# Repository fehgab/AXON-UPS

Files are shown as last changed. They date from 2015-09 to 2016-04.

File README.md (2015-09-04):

AXON-UPS
========

## Introduction

AXON-UPS is a sigle-board-computer, which acts as a functional unit.
Its main purpose to provide intelligent UPS functionality to linux based single board computers, such as Raspberry Pi, Banana Pi, Orange Pi, Cubieboard, etc.

This device is a tiny member of the big family of intelligent UPSs that is a wide range of devices from simple desktop variants to the professional server UPSs.
It is developed as a thesis work, but the developer is willing to create a product, that is able to delivers real values to real customers. So the functionalities of the several releases of the product will be collected from potential users of it.
    
This document summerize the whole project, including the requirements specification, the development roadmap and some references to existing alternatives of the product and solutions might worth to study during the design phase.

## Roadmap

1. Definition of the thesis topic

    - Deadline: 01.09.2015

2. Phase I:

    - Scouting, reading literature, collecting ideas, existing solutions, etc.

    - Defining the features, release planning

    - Designing the device, start development:

        - schematics of the circuit
        - breadboard prototype
        - firmware/software
        - prototype testing

    - Deadline:
        dec 15

2. Phase II:
    - Finish development:

        - PCB layout

    - Manufacturing and assembling the PCBs (prototype)
    - Testing
    - Completed documentation, finished thesis work
    - Deliver the working v1.0 product
    - Deadline: június 30

## Next Actions

- Involving potential product end-users into the requirement specification
- Collecting ideas and required features

    - Collecting and studying Universal UPS features, functionalities
    - Study the unix upsd and similar tools

- Defining the scope for v1.0 product

## Requirements

### Mandatory

- AXON-UPS must provide the regulated (configurable) voltage and current to the connected devices:

    - Voltages:
        - 5 VDC
        - 3.3 VDC
    - Current: min. 3A

- Power Outage Detection and management:
    - In case of outage a controlled switch-off procedure must be executed successfully
    - In case of outage the UPS must be able to supply the host computer until that is successfully shut down.
    - Time and mode is configurable
    - Auto-shut down mode:
        - shut down immediately (timing is configurable),
        - keep-alive mode until there is enough power, then shut-down.

- Intentional switch on/off process management:

    - Execute the startup and shut-down process in case of order: switch ON/OFF (mechanical, remote command).

    - via...
        - mechanical switch,
        - remote command.

- In case the shut-down process has been started either intentionally or via power outage, the swithch on/off can be activated only after the ongoing shut-down process successfully finished.

- Display/monitor status:

    - LED,
    - software,
    - configurable.

- USB communication channel with serial protocol:

    - communicates with the host computer,
    - configurability,
    - alert/watch-dog function,
    - log transfer,
    - etc.

- Configurability via
    - firmware
    - jumpers

### Optional

- Supervise and log the outages, brown-outs, 
- Interrupt jumper/connector  to rPi GPIO, etc.
- ROS compatible
- Using solar cells 

## References

- [Raspberry Pi UPS: A Very Simple Solution](http://homediyelectronics.com/projects/raspberrypi/ups/)
- [Belkin Universal UPS protocol description](http://www.mscs.dal.ca/~selinger/ups/belkin-universal-ups.html)
- [Network UPS Tools](https://en.wikipedia.org/wiki/Network_UPS_Tools)
- [V-USB - A software-only implementation of a low-speed USB device for Atmel’s AVR®](https://www.obdev.at/products/vusb/index.html)
- [Controlled Shutdown at Power Failure](https://www.raspberrypi.org/forums/viewtopic.php?f=37&t=50470)

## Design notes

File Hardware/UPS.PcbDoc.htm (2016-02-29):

Reporting Options

# File in Previous Format

Date | : | 2016.02.29.
Time | : | 16:59:47
Filename | : | D:\Cloud\Github\AXON-UPS\Hardware\UPS.PcbDoc

Version | Warning

This file was generated by an earlier version of the software

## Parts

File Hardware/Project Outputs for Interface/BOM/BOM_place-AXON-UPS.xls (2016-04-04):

Designator | CompType | Value | Package | Note | Distributor | Order Code | Comment | Description | Lomex NR
B1 |  |  |  |  |  |  | BAT
C1 |  | 100nF |  |  |  |  | 100nF | Capacitor | 82-07-32
C2 |  | 100nF |  |  |  |  | 100nF | Capacitor | 82-07-32
C3 |  | 100nF |  |  |  |  | 100nF | Capacitor | 82-07-32
C4 |  | 100nF |  |  |  |  | 100nF | Capacitor | 82-07-32
C5 | CC0805KRX7R9BB472 | 4n7 50V X7R | 0805 |  | Lomex | 82-00-71 | 4n7 50V X7R | SMD kondenzátorok
C6 | CC0805KRX7R9BB472 | 4n7 50V X7R | 0805 |  | Lomex | 82-00-71 | 4n7 50V X7R | SMD kondenzátorok
C7 |  | 6800uF |  |  |  |  | 5600uF | Capacitor
C8 |  | 10uF |  |  |  |  | 10uF | Capacitor | 82-08-32
C9 |  | 47uF |  |  |  |  | 47uF | Capacitor | 82-08-04
C10 |  | 100nF |  |  |  |  | 100nF | Capacitor | 82-07-32
C11 |  | 100nF |  |  |  |  | 100nF | Capacitor | 82-07-32
C12 |  | 10uF |  |  |  |  | 10uF | Capacitor | 82-08-32
C13 |  | 10uF |  |  |  |  | 10uF | Capacitor | 82-08-32
C14 |  | 1u2 |  |  |  |  | 1u2 | Capacitor | 82-05-93
C15 |  | 100nF |  |  |  |  | 100nF | Capacitor | 82-07-32
C16 |  | 1u2 |  |  |  |  | 1u2 | Capacitor | 82-05-93
C17 |  | 1nF |  |  |  |  | 1nF | Capacitor | 82-00-75
C18 |  | 22pF |  |  |  |  | 22pF | Capacitor | 82-09-18
C19 |  | 22pF |  |  |  |  | 22pF | Capacitor | 82-09-18
C20 |  | 100nF |  |  |  |  | 100nF | Capacitor | 82-07-32
C21 |  | 1uF |  |  |  |  | 1uF | Capacitor | 82-05-11
C22 |  | 10uF |  |  |  |  | 10uF | Capacitor | 82-08-32
C23 |  | 10uF |  |  |  |  | 10uF | Capacitor | 82-08-32
C24 |  | 10nF |  |  |  |  | 10nF | Capacitor | 82-05-66
C25 |  | 10nF |  |  |  |  | 10nF | Capacitor | 82-05-66
C26 | CC0805KPX7R9BB104 | 100nF 50V | 0805 | 10% X7R | Lomex | 82-07-32 | 100nF 50V | SMD kondenzátorok
C27 | CL31A106KAHNNNE | 10uF 25V | 1206 | 10% X5R | Lomex | 82-07-90 | 10uF 25V | SMD kondenzátorok
C28 | CC0805KRX7R8BB103 | 10nF 10% 25V X7R | 0805 |  | Lomex | 82-05-66 | 10nF 10% 25V X7R | SMD kondenzátorok
C29 | CC0805KPX7R9BB104 | 100nF 50V | 0805 | 10% X7R | Lomex | 82-07-32 | 100nF 50V | SMD kondenzátorok
C30 | CC0805KRX7R9BB472 | 4n7 50V X7R | 0805 |  | Lomex | 82-00-71 | 4n7 50V X7R | SMD kondenzátorok
C31 | CC0805KPX7R9BB104 | 100nF 50V | 0805 | 10% X7R | Lomex | 82-07-32 | 100nF 50V | SMD kondenzátorok
C32 | CC0805JRNP09BN331 | 330pF 50V NP0 | 0805 |  | Lomex | 82-01-07 | 330pF 50V NP0 | SMD kondenzátorok
C33 | CC0805JRNP09BN331 | 330pF 50V NP0 | 0805 |  | Lomex | 82-01-07 | 330pF 50V NP0 | SMD kondenzátorok
C34 | CC0805KPX7R9BB104 | 100nF 50V | 0805 | 10% X7R | Lomex | 82-07-32 | 100nF 50V | SMD kondenzátorok
C35 | CC0805KPX7R9BB104 | 100nF 50V | 0805 | 10% X7R | Lomex | 82-07-32 | 100nF 50V | SMD kondenzátorok
C36 | CC0805JRNP09BN102 | 1n 50V NP0 | 0805 |  | Lomex | 82-01-13 | 1n 50V NP0
C37 | CC0805JRNP09BN102 | 1n 50V NP0 | 0805 |  | Lomex | 82-01-13 | 1n 50V NP0
C38 | CC0805JRNP09BN102 | 1n 50V NP0 | 0805 |  | Lomex | 82-01-13 | 1n 50V NP0
C39 | CC0805JRNP09BN102 | 1n 50V NP0 | 0805 |  | Lomex | 82-01-13 | 1n 50V NP0
C40 | CC0805JRNP09BN331 | 330pF 50V NP0 | 0805 |  | Lomex | 82-01-07 | 330pF 50V NP0 | SMD kondenzátorok
C41 | CC0805JRNP09BN331 | 330pF 50V NP0 | 0805 |  | Lomex | 82-01-07 | 330pF 50V NP0 | SMD kondenzátorok
C42 | CC0805JRNP09BN331 | 330pF 50V NP0 | 0805 |  | Lomex | 82-01-07 | 330pF 50V NP0 | SMD kondenzátorok
C43 | CC0805JRNP09BN331 | 330pF 50V NP0 | 0805 |  | Lomex | 82-01-07 | 330pF 50V NP0 | SMD kondenzátorok
C44 | CC0805KPX7R9BB104 | 100nF 50V | 0805 | 10% X7R | Lomex | 82-07-32 | 100nF 50V | SMD kondenzátorok
C45 | CC0805JRNP09BN102 | 1n 50V NP0 | 0805 |  | Lomex | 82-01-13 | 1n 50V NP0
C46 | CC0805JRNP09BN102 | 1n 50V NP0 | 0805 |  | Lomex | 82-01-13 | 1n 50V NP0
C47 | CC0805KPX7R9BB104 | 100nF 50V | 0805 | 10% X7R | Lomex | 82-07-32 | 100nF 50V | SMD kondenzátorok
C48 | CC0805JRNP09BN102 | 1n 50V NP0 | 0805 |  | Lomex | 82-01-13 | 1n 50V NP0
C49 | CC0805JRNP09BN102 | 1n 50V NP0 | 0805 |  | Lomex | 82-01-13 | 1n 50V NP0
C50 | CC0805JRNP09BN331 | 330pF 50V NP0 | 0805 |  | Lomex | 82-01-07 | 330pF 50V NP0 | SMD kondenzátorok
C51 | CC0805JRNP09BN331 | 330pF 50V NP0 | 0805 |  | Lomex | 82-01-07 | 330pF 50V NP0 | SMD kondenzátorok
C52 |  | 100nF |  |  |  |  | 100nF | Capacitor | 82-07-32
C53 |  | 1nF |  |  |  |  | 500pF | Capacitor
CN1 | USB-B-04PFHTW |  | USB-B 4P ANYA 90° | HORIZONTAL PCB FEMALE NYÁK 90° | Lomex | 43-14-75 | USB-B-04PFHTW
CN2 | USB-B-04PFHTW |  | USB-B 4P ANYA 90° | HORIZONTAL PCB FEMALE NYÁK 90° | Lomex | 43-14-75 | USB-B-04PFHTW
CN3 | CPM5.08/5SQ, CPF5.08/5 | 5P | RM5.08 |  | Lomex | 43-07-79, 43-07-78 | Dugos Sorkapocs 5 | SORKAPOCS 5 P RM5.08 CSAPSORLÉC 90° ZÁRT 12A
CN4 | USB-B-04PFHTW |  | USB-B 4P ANYA 90° | HORIZONTAL PCB FEMALE NYÁK 90° | Lomex | 43-14-75 | USB-B-04PFHTW
D1 |  |  |  |  |  |  | 1N5819 | NXP - PMEG3020EJ,115 - SCHOTTKY RECT 30V 2A SOD323F
D2 |  |  |  |  |  |  | 1N5819 | NXP - PMEG3020EJ,115 - SCHOTTKY RECT 30V 2A SOD323F
D3 |  |  |  |  |  |  | 1N5819 | NXP - PMEG3020EJ,115 - SCHOTTKY RECT 30V 2A SOD323F
F1 | PTF/15, BS/140NA, | 3A "F" |  | BIZTOSITÉK FOGL. (STE) (503.300) 5x20 + fedél (503.310) + bizt. | Lomex | 44-01-84, 44-01-85, 44-00-57 | 3A "F" | Fuse
F2 | PTF/15, BS/140NA, | 5A "F" |  | BIZTOSITÉK FOGL. (STE) (503.300) 5x20 + fedél (503.310) + bizt. | Lomex | 44-01-84, 44-01-85, 44-00-57 | 5A "F" | Fuse
JP1 |  |  |  |  |  |  | JUMPER | Jumper Wire
JP2 |  |  |  |  |  |  | JUMPER | Jumper Wire
JP3 |  |  |  |  |  |  | JUMPER | Jumper Wire
L1 |  | 86uH |  |  |  |  | 86uH | Inductor
L2 |  | 10uH |  |  |  |  | 10uH | Inductor | 55-00-65
L3 |  | 10uH |  |  |  |  | 10uH | Inductor | 55-00-65
L4 | CB05YTYH221 | 220ohm/100MHz, 0.08R (2A) | 0805 |  | Lomex | 93-03-48 | 220ohm/100MHz, 0.08R (2A) | SMD Ferrit Bead 220ohm/100MHz
LED1 | KP-3216SRD-PRV | RED | 1206 |  | Lomex | 95-00-28 | RED | LED
LED2 | KP-3216SGD | GRE | 1206 |  | Lomex | 95-00-26 | GRE | LED
LED3 | KP-3216SRD-PRV | RED | 1206 |  | Lomex | 95-00-28 | RED | LED
LED4 | KP-3216SGD | GRE | 1206 |  | Lomex | 95-00-26 | GRE | LED
LED5 | KP-3216SGD | GRE | 1206 |  | Lomex | 95-00-26 | GRE | LED
LED6 | KP-3216SRD-PRV | RED | 1206 |  | Lomex | 95-00-28 | RED | LED
LED7 | KP-3216SGD | GRE | 1206 |  | Lomex | 95-00-26 | GRE | LED
P1 |  |  |  |  |  |  | TMS320F28027 | Processor
Q1 |  |  |  |  |  |  | BC556 | PNP tranzisztor | 21-06-74
Q2 |  |  |  |  |  |  | BD139 | NPN tranzisztor | 21-11-08
Q3 |  |  |  |  |  |  | BD140 | PNP tranzisztor | 21-11-09
Q4 |  |  |  |  |  |  | BC546 | NPN tranzisztor | 21-11-18
Q5 |  |  |  |  |  |  | BD139 | NPN tranzisztor | 21-11-08
Q6 |  |  |  |  |  |  | BD140 | PNP tranzisztor | 21-11-09
Q7 |  |  |  |  |  |  | IRF9530N | P-MOSFET | 21-01-94
Q8 |  |  |  |  |  |  | BC546 | NPN tranzisztor | 21-11-18
Q9 |  |  |  |  |  |  | IRL7833 | N-FET | 82-07-81
Q10 |  |  |  |  |  |  | IRL7833 | N-FET | 82-07-81
Q11 |  |  |  |  |  |  | SN74LVC244A
Q12 |  |  |  |  |  |  | HC49/4HSMX | kristály
Q13 |  |  |  |  |  |  | TPS73633DCQR | proci táp 3V3
Q14 |  |  |  |  |  |  | TPS73633DCQR | proci táp 3V3
R1 |  | 1K |  |  |  |  | 1K | Resistor
R2 |  | 1K5 |  |  |  |  | 1K5 | Resistor
R3 |  | 2 |  |  |  |  | 2 | Resistor
R4 |  | 10K |  |  |  |  | 10K | Resistor
R5 |  | 1K |  |  |  |  | 1K | Resistor
R6 |  | 2K2 |  |  |  |  | 2K2 | Resistor
R7 |  | 10K |  |  |  |  | 10K | Resistor
R8 |  | 2K2 |  |  |  |  | 2K2 | Resistor
R9 |  | 2 |  |  |  |  | 2 | Resistor
R10 |  | 10K |  |  |  |  | 10K | Resistor
R11 |  | 10K |  |  |  |  | 10K | Resistor
R12 |  | 1M |  |  |  |  | 1M | Resistor
R13 |  | 0 |  |  |  |  | 0 | Resistor
R14 |  | 1M |  |  |  |  | 1M | Resistor
R15 |  | 0 |  |  |  |  | 0 | Resistor
R16 |  | 0 |  |  |  |  | 0 | Resistor
R17 |  | 10K |  |  |  |  | 10K | Resistor
R18 |  | 0 |  |  |  |  | 0 | Resistor
R19 |  | 2K2 |  |  |  |  | 2K2 | Resistor
R20 |  | 10K |  |  |  |  | 10K | Resistor
R21 |  | 0 |  |  |  |  | 0 | Resistor
R22 |  | 0 |  |  |  |  | 0 | Resistor
R23 |  | 3K3 |  |  |  |  | 3K3 | Resistor
R24 |  | 3K3 |  |  |  |  | 3K3 | Resistor
R25 |  | 100K |  |  |  |  | 100K | Resistor
R26 |  | 1M |  |  |  |  | 1M | Resistor
R27 | CR-05JL7--390R | 390R | 0805 |  | Lomex | 81-10-82 | 390R
R28 | CR-05JL7--390R | 390R | 0805 |  | Lomex | 81-10-82 | 390R
R29 | CR-05JL7--390R | 390R | 0805 |  | Lomex | 81-10-82 | 390R
R30 | CR-05JL7--390R | 390R | 0805 |  | Lomex | 81-10-82 | 390R
R31 | CR-05JL7--390R | 390R | 0805 |  | Lomex | 81-10-82 | 390R
R32 | CR-05JL7---4K7 | 4K70 5% | 0805 |  | Lomex | 81-10-95 | 4K70 5%
R33 | CR-05JL7---33R | 33R0 5% | 0805 | 0.125W | Lomex | 81-10-69 | 33R0 5%
R34 | CR-05JL7---33R | 33R0 5% | 0805 | 0.125W | Lomex | 81-10-69 | 33R0 5%
R35 | CR-05JL7--390R | 390R | 0805 |  | Lomex | 81-10-82 | 390R
R36 | CR-05FL7---10K | 10K0 1% | 0805 |  | Lomex | 80-10-98 | 10K0 1%
R37 | CR-05JL7----1M | 1M | 0805 |  | Lomex | 81-11-22 | 1M
R38 | CR-05JL7--390R | 390R | 0805 |  | Lomex | 81-10-82 | 390R
R39 | CR-05FL7---3K3 | 3k3 1% | 0805 |  | Lomex | 80-10-92 | 3k3 1%
R40 | CR-05FL7---3K3 | 3k3 1% | 0805 |  | Lomex | 80-10-92 | 3k3 1%
R41 |  | 5K6 |  |  |  |  | 5K6 | Resistor
R42 | CR-05FL7---2K7 | 2k7 1% | 0805 |  | Lomex | 80-10-91 | 2k7 1%
R43 | CR-05FL7---2K4 | 1K8 1% | 0805 |  | Lomex | 80-14-00 | 1K8 1%
R44 |  | 5K6 |  |  |  |  | 5K6 | Resistor
R45 | CR-05FL7---2K7 | 2k7 1% | 0805 |  | Lomex | 80-10-91 | 2k7 1%
R46 | CR-05FL7---2K4 | 1k8 1% | 0805 |  | Lomex | 80-14-00 | 1k8 1%
R47 |  | 3K3 |  |  |  |  | 3K3 | Resistor
R48 |  | 2K5 |  |  |  |  | 2K5 | Resistor
R49 |  | 10K |  |  |  |  | 10K | Resistor
R50 | CR-05FL7---3K3 | 3k3 1% | 0805 |  | Lomex | 80-10-92 | 3k3 1%
R51 |  | 3K |  |  |  |  | 3K | Resistor
R52 | CR-05FL7---3K3 | 3k3 1% | 0805 |  | Lomex | 80-10-92 | 3k3 1%
R53 |  | 3K3 |  |  |  |  | 3K3 | Resistor
R54 |  | 3K3 |  |  |  |  | 3K3 | Resistor
R55 |  | 2K7 |  |  |  |  | 2K7 | Resistor
R56 |  | 10K |  |  |  |  | 10K | Resistor
R57 | CR-05FL7---3K3 | 3k3 1% | 0805 |  | Lomex | 80-10-92 | 3k3 1%
R58 |  | 3K3 |  |  |  |  | 3K3 | Resistor
R59 |  | 3K3 |  |  |  |  | 3K3 | Resistor
R60 | CR-05FL7---3K3 | 10K | 0805 |  | Lomex | 80-10-92 | 10K
R61 |  | 5K6 |  |  |  |  | 5K6 | Resistor
R62 |  | 5K6 |  |  |  |  | 5K6 | Resistor
R63 |  | 5K |  |  |  |  | 5K | Resistor
R64 |  | 5K |  |  |  |  | 5K | Resistor
R65 | CR-05FL7---3K3 | 3k3 1% | 0805 |  | Lomex | 80-10-92 | 3k3 1%
R66 | CR-05FL7---3K3 | 10K | 0805 |  | Lomex | 80-10-92 | 10K
R67 |  | 3K3 |  |  |  |  | 3K3 | Resistor
R68 |  | 0 |  |  |  |  | 0 | Resistor
R69 |  | 2K5 |  |  |  |  | 2K5 | Resistor
R70 |  | 2K7 |  |  |  |  | 2K7 | Resistor
TP7 |  |  |  |  |  |  | Testpoint
TP8 |  |  |  |  |  |  | Testpoint
TP9 |  |  |  |  |  |  | Testpoint
TP10 |  |  |  |  |  |  | Testpoint
TP11 |  |  |  |  |  |  | Testpoint
U1 |  |  |  |  |  |  | MCP120 | Voltage detector
U2 | FT232RL |  | SSOP-28 | USB UART IC | Lomex | 89-21-46 | FT232RL | USB - UART IC
U3 | USB6B1 |  | SOIC-8 | TVS diode | RS components | 687-1075 | USB6B1
U4 | FAN4174IS5X |  | SOT-23-5 |  | RS components |  | FAN4174IS5X | FAN4174IS5X
U5 | FAN4174IS5X |  | SOT-23-5 |  | RS components |  | FAN4174IS5X | FAN4174IS5X
U6 |  |  |  |  |  |  | LM2903D | komparátor
U7 | FAN4174IS5X |  | SOT-23-5 |  | RS components |  | FAN4174IS5X | FAN4174IS5X
U8 | FAN4174IS5X |  | SOT-23-5 |  | RS components |  | FAN4174IS5X | FAN4174IS5X
U9 |  |  |  |  |  |  | ASC711 | Áramméro
ZD1 | BZX85C5V6 |  | DO-41 | 5.6 V 1.3 W | Lomex | 18-01-92 | BZX85C5V6 | Zener Diode 5V6 1.3W DO-41

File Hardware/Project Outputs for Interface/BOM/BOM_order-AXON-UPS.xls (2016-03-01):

CompType | Package | Value | Distributor | Order Code | Lomex NR | Quantity | Designator | Note | Comment | Description
 |  |  |  |  |  | 1 | B1 |  | BAT
 |  |  |  |  |  | 1 | P1 |  | TMS320F28027 | Processor
 |  |  |  |  |  | 1 | Q11 |  | SN74LVC244A
 |  |  |  |  |  | 1 | Q12 |  | HC49/4HSMX | kristály
 |  |  |  |  |  | 1 | U1 |  | MCP120 | Voltage detector
 |  |  |  |  |  | 1 | U6 |  | LM2903D | komparátor
 |  |  |  |  |  | 1 | U9 |  | ASC711 | Áramméro
 |  |  |  |  |  | 2 | Q13, Q14 |  | TPS73633DCQR | proci táp 3V3
 |  |  |  |  |  | 3 | D1, D2, D3 |  | 1N5819 | NXP - PMEG3020EJ,115 - SCHOTTKY RECT 30V 2A SOD323F
 |  |  |  |  |  | 3 | JP1, JP2, JP3 |  | JUMPER | Jumper Wire
 |  |  |  |  |  | 5 | TP7, TP8, TP9, TP10, TP11 |  | Testpoint
 |  |  |  |  | 21-01-94 | 1 | Q7 |  | IRF9530N | P-MOSFET
 |  |  |  |  | 21-06-74 | 1 | Q1 |  | BC556 | PNP tranzisztor
 |  |  |  |  | 21-11-08 | 2 | Q2, Q5 |  | BD139 | NPN tranzisztor
 |  |  |  |  | 21-11-09 | 2 | Q3, Q6 |  | BD140 | PNP tranzisztor
 |  |  |  |  | 21-11-18 | 2 | Q4, Q8 |  | BC546 | NPN tranzisztor
 |  |  |  |  | 82-07-81 | 2 | Q9, Q10 |  | IRL7833 | N-FET
 |  | 0 |  |  |  | 1 | R68 |  | 0 | Resistor
 |  | 0 |  |  |  | 6 | R13, R15, R16, R18, R21, R22 |  | 0 | Resistor
 |  | 100K |  |  |  | 1 | R25 |  | 100K | Resistor
 |  | 100nF |  |  | 82-07-32 | 9 | C1, C2, C3, C4, C10, C11, C15, C20, C52 |  | 100nF | Capacitor
 |  | 10K |  |  |  | 4 | R49, R56, R60, R66 |  | 10K | Resistor, Resistor, [NoValue], [NoValue]
 |  | 10K |  |  |  | 6 | R4, R7, R10, R11, R17, R20 |  | 10K | Resistor
 |  | 10nF |  |  | 82-05-66 | 2 | C24, C25 |  | 10nF | Capacitor
 |  | 10uF |  |  | 82-08-32 | 5 | C8, C12, C13, C22, C23 |  | 10uF | Capacitor
 |  | 10uH |  |  | 55-00-65 | 2 | L2, L3 |  | 10uH | Inductor
 |  | 1K |  |  |  | 2 | R1, R5 |  | 1K | Resistor
 |  | 1K5 |  |  |  | 1 | R2 |  | 1K5 | Resistor
 |  | 1M |  |  |  | 3 | R12, R14, R26 |  | 1M | Resistor
 |  | 1nF |  |  | 82-00-75 | 1 | C17 |  | 1nF | Capacitor
 |  | 1u2 |  |  | 82-05-93 | 2 | C14, C16 |  | 1u2 | Capacitor
 |  | 1uF |  |  | 82-05-11 | 1 | C21 |  | 1uF | Capacitor
 |  | 2 |  |  |  | 2 | R3, R9 |  | 2 | Resistor
 |  | 22pF |  |  | 82-09-18 | 2 | C18, C19 |  | 22pF | Capacitor
 |  | 2K2 |  |  |  | 3 | R6, R8, R19 |  | 2K2 | Resistor
 |  | 2K5 |  |  |  | 2 | R48, R69 |  | 2K5 | Resistor
 |  | 2K7 |  |  |  | 2 | R55, R70 |  | 2K7 | Resistor
 |  | 3K |  |  |  | 1 | R51 |  | 3K | Resistor
 |  | 3K3 |  |  |  | 8 | R23, R24, R47, R53, R54, R58, R59, R67 |  | 3K3 | Resistor
 |  | 47uF |  |  | 82-08-04 | 1 | C9 |  | 47uF | Capacitor
 |  | 500pF |  |  |  | 1 | C53 |  | 500pF | Capacitor
 |  | 5K |  |  |  | 2 | R63, R64 |  | 5K | Resistor
 |  | 5K6 |  |  |  | 4 | R41, R44, R61, R62 |  | 5K6 | Resistor
 |  | 6800uF |  |  |  | 1 | C7 |  | 5600uF | Capacitor
 |  | 86uH |  |  |  | 1 | L1 |  | 86uH | Inductor
BZX85C5V6 | DO-41 |  | Lomex | 18-01-92 |  | 1 | ZD1 | 5.6 V 1.3 W | BZX85C5V6 | Zener Diode 5V6 1.3W DO-41
CB05YTYH221 | 0805 | 220ohm/100MHz, 0.08R (2A) | Lomex | 93-03-48 |  | 1 | L4 |  | 220ohm/100MHz, 0.08R (2A) | SMD Ferrit Bead 220ohm/100MHz
CC0805JRNP09BN102 | 0805 | 1n 50V NP0 | Lomex | 82-01-13 |  | 8 | C36, C37, C38, C39, C45, C46, C48, C49 |  | 1n 50V NP0
CC0805JRNP09BN331 | 0805 | 330pF 50V NP0 | Lomex | 82-01-07 |  | 8 | C32, C33, C40, C41, C42, C43, C50, C51 |  | 330pF 50V NP0 | SMD kondenzátorok
CC0805KPX7R9BB104 | 0805 | 100nF 50V | Lomex | 82-07-32 |  | 7 | C26, C29, C31, C34, C35, C44, C47 | 10% X7R | 100nF 50V | SMD kondenzátorok
CC0805KRX7R8BB103 | 0805 | 10nF 10% 25V X7R | Lomex | 82-05-66 |  | 1 | C28 |  | 10nF 10% 25V X7R | SMD kondenzátorok
CC0805KRX7R9BB472 | 0805 | 4n7 50V X7R | Lomex | 82-00-71 |  | 3 | C5, C6, C30 |  | 4n7 50V X7R | SMD kondenzátorok
CL31A106KAHNNNE | 1206 | 10uF 25V | Lomex | 82-07-90 |  | 1 | C27 | 10% X5R | 10uF 25V | SMD kondenzátorok
CPM5.08/5SQ, CPF5.08/5 | RM5.08 | 5P | Lomex | 43-07-79, 43-07-78 |  | 1 | CN3 |  | Dugos Sorkapocs 5 | SORKAPOCS 5 P RM5.08 CSAPSORLÉC 90° ZÁRT 12A
CR-05FL7---2K4 | 0805 | 1K8 1% | Lomex | 80-14-00 |  | 2 | R43, R46 |  | 1K8 1%
CR-05FL7---2K7 | 0805 | 2k7 1% | Lomex | 80-10-91 |  | 2 | R42, R45 |  | 2k7 1%
CR-05FL7---3K3 | 0805 | 3k3 1% | Lomex | 80-10-92 |  | 6 | R39, R40, R50, R52, R57, R65 |  | 3k3 1%
CR-05FL7---10K | 0805 | 10K0 1% | Lomex | 80-10-98 |  | 1 | R36 |  | 10K0 1%
CR-05JL7--390R | 0805 | 390R | Lomex | 81-10-82 |  | 7 | R27, R28, R29, R30, R31, R35, R38 |  | 390R
CR-05JL7---4K7 | 0805 | 4K70 5% | Lomex | 81-10-95 |  | 1 | R32 |  | 4K70 5%
CR-05JL7---33R | 0805 | 33R0 5% | Lomex | 81-10-69 |  | 2 | R33, R34 | 0.125W | 33R0 5%
CR-05JL7----1M | 0805 | 1M | Lomex | 81-11-22 |  | 1 | R37 |  | 1M
FAN4174IS5X | SOT-23-5 |  | RS components |  |  | 4 | U4, U5, U7, U8 |  | FAN4174IS5X | FAN4174IS5X
FT232RL | SSOP-28 |  | Lomex | 89-21-46 |  | 1 | U2 | USB UART IC | FT232RL | USB - UART IC
KP-3216SGD | 1206 | GRE | Lomex | 95-00-26 |  | 4 | LED2, LED4, LED5, LED7 |  | GRE | LED
KP-3216SRD-PRV | 1206 | RED | Lomex | 95-00-28 |  | 3 | LED1, LED3, LED6 |  | RED | LED
PTF/15, BS/140NA, |  | 3A "F" | Lomex | 44-01-84, 44-01-85, 44-00-57 |  | 1 | F1 | BIZTOSITÉK FOGL. (STE) (503.300) 5x20 + fedél (503.310) + bizt. | 3A "F" | Fuse
PTF/15, BS/140NA, |  | 5A "F" | Lomex | 44-01-84, 44-01-85, 44-00-57 |  | 1 | F2 | BIZTOSITÉK FOGL. (STE) (503.300) 5x20 + fedél (503.310) + bizt. | 5A "F" | Fuse
USB6B1 | SOIC-8 |  | RS components | 687-1075 |  | 1 | U3 | TVS diode | USB6B1
USB-B-04PFHTW | USB-B 4P ANYA 90° |  | Lomex | 43-14-75 |  | 3 | CN1, CN2, CN4 | HORIZONTAL PCB FEMALE NYÁK 90° | USB-B-04PFHTW
 |  |  |  |  |  | 177

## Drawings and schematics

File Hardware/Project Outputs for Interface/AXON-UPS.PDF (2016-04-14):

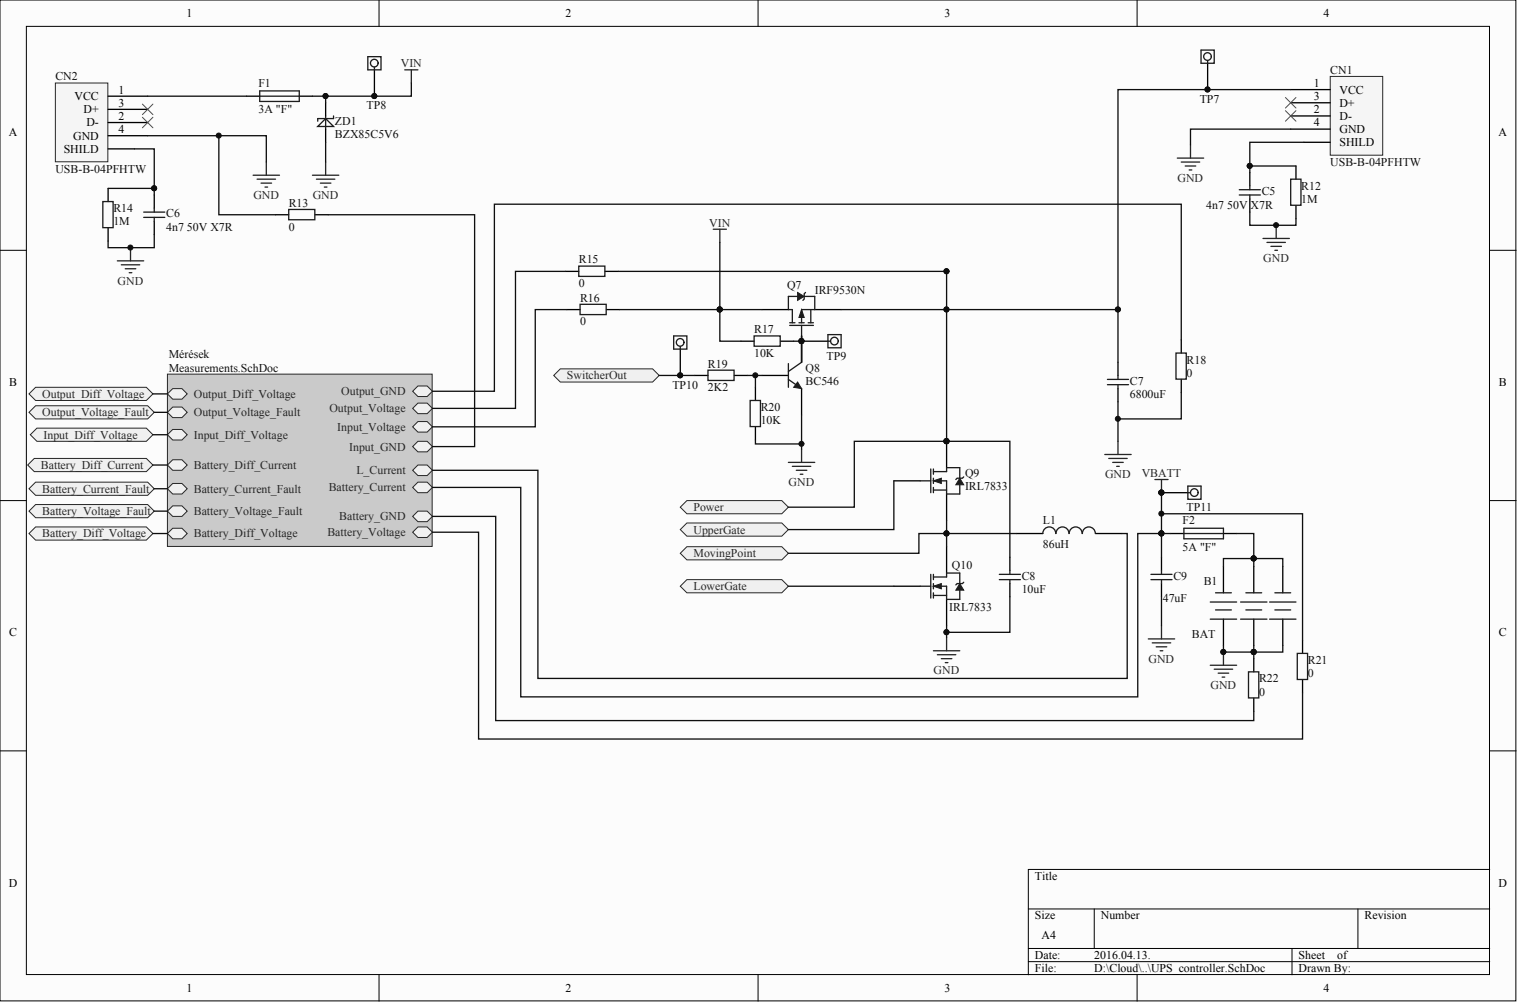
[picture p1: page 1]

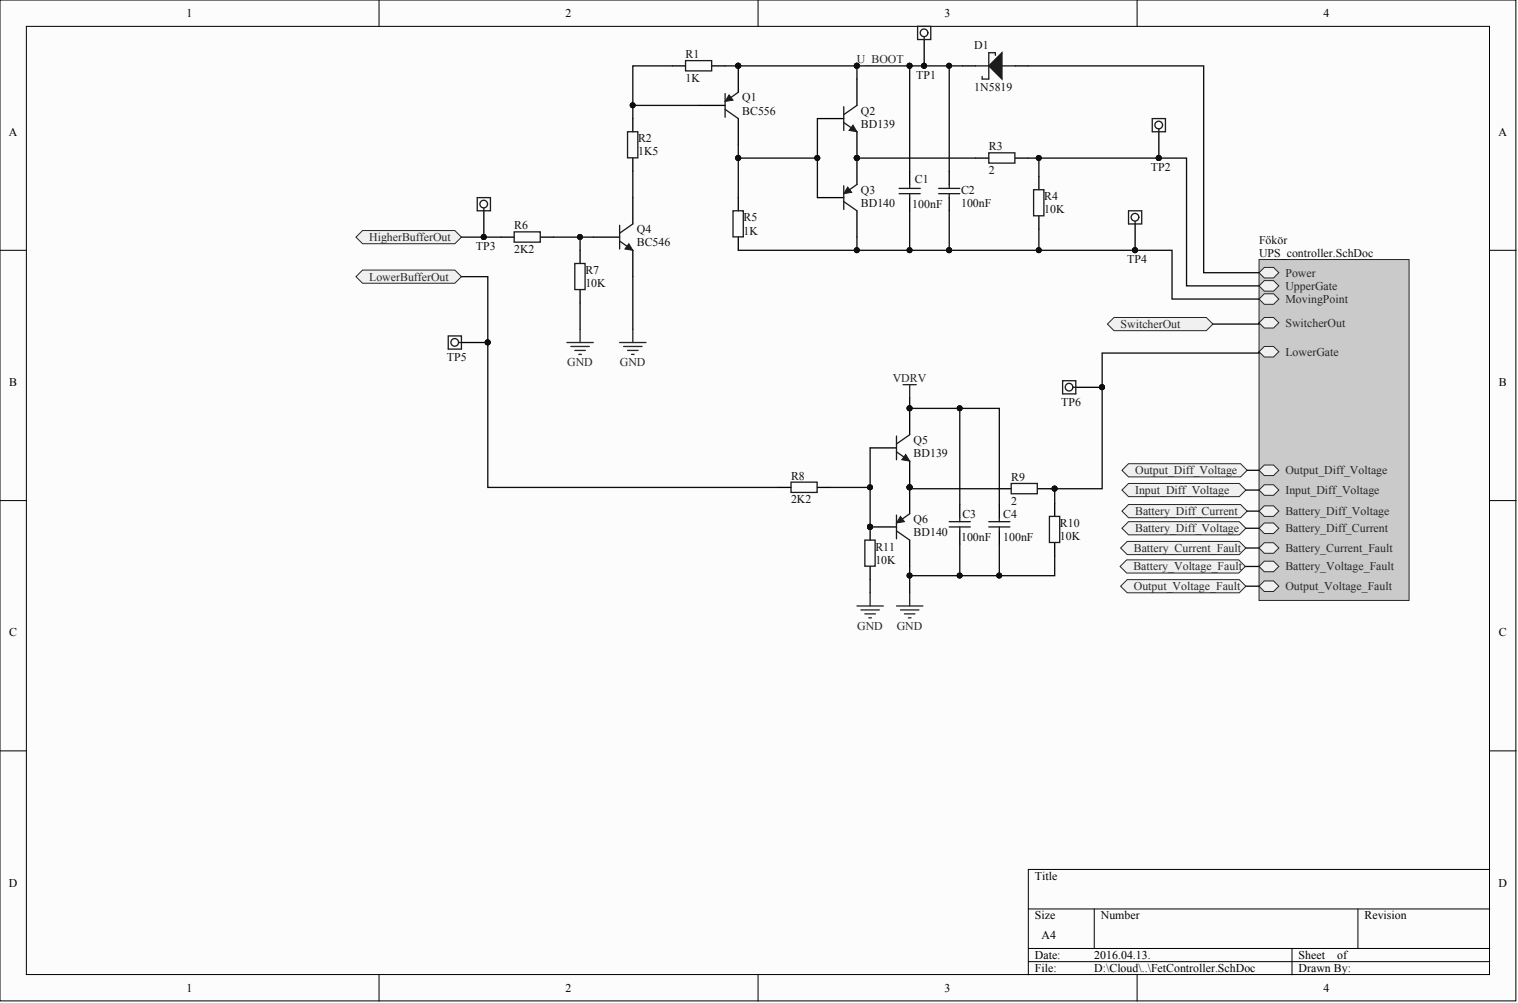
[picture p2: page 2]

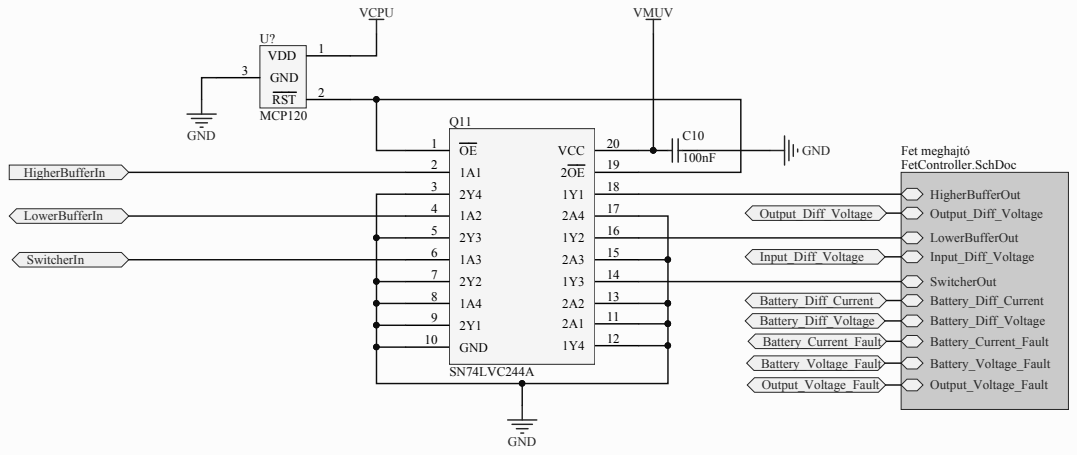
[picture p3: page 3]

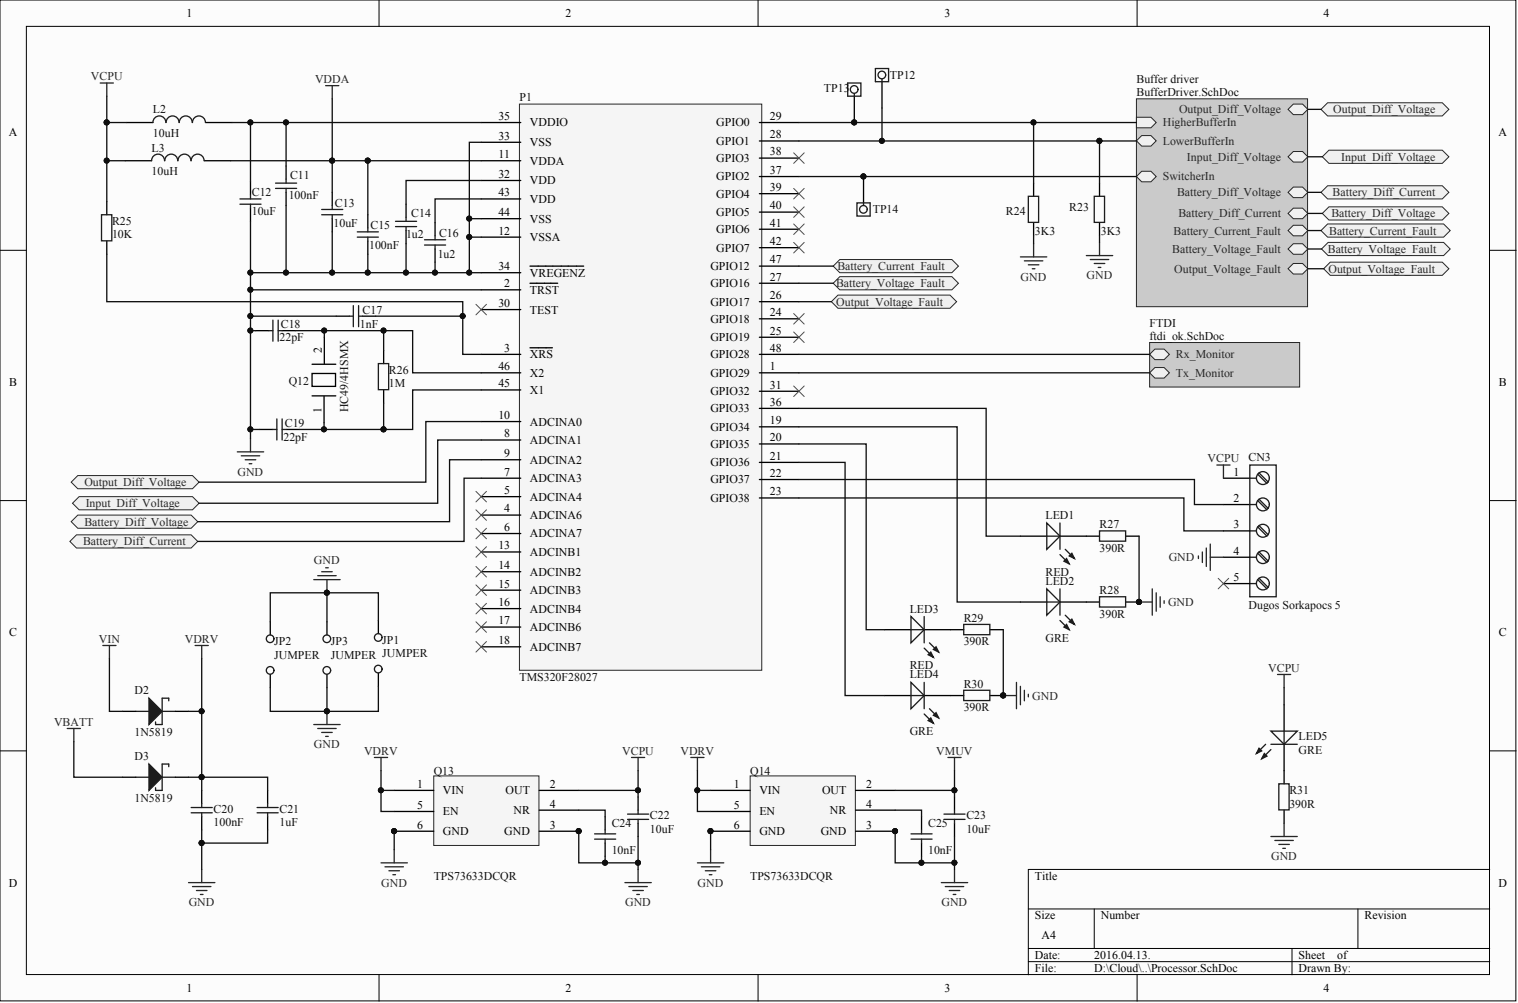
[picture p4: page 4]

VSS 33
VDDA 11

C11 | | | VDD 32

VDD 43
VSS 44
VSSA 12

VREGENZ 34
TRST 2
TEST 30

ADCINA0 10
ADCINA1 8
ADCINA2 9

GND | | ADCINA3 7

ADCINA4 5 | | | 2

LED1 | 3

ADCINB1 13 | | RED LED2

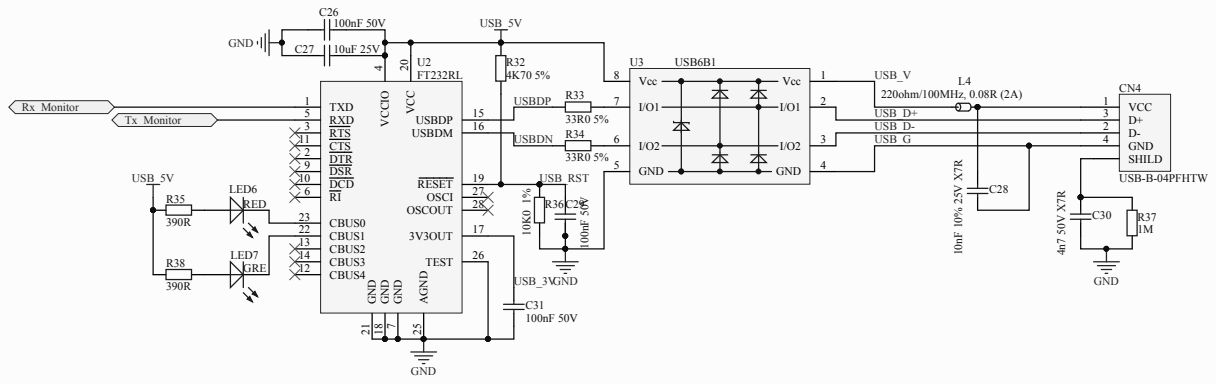
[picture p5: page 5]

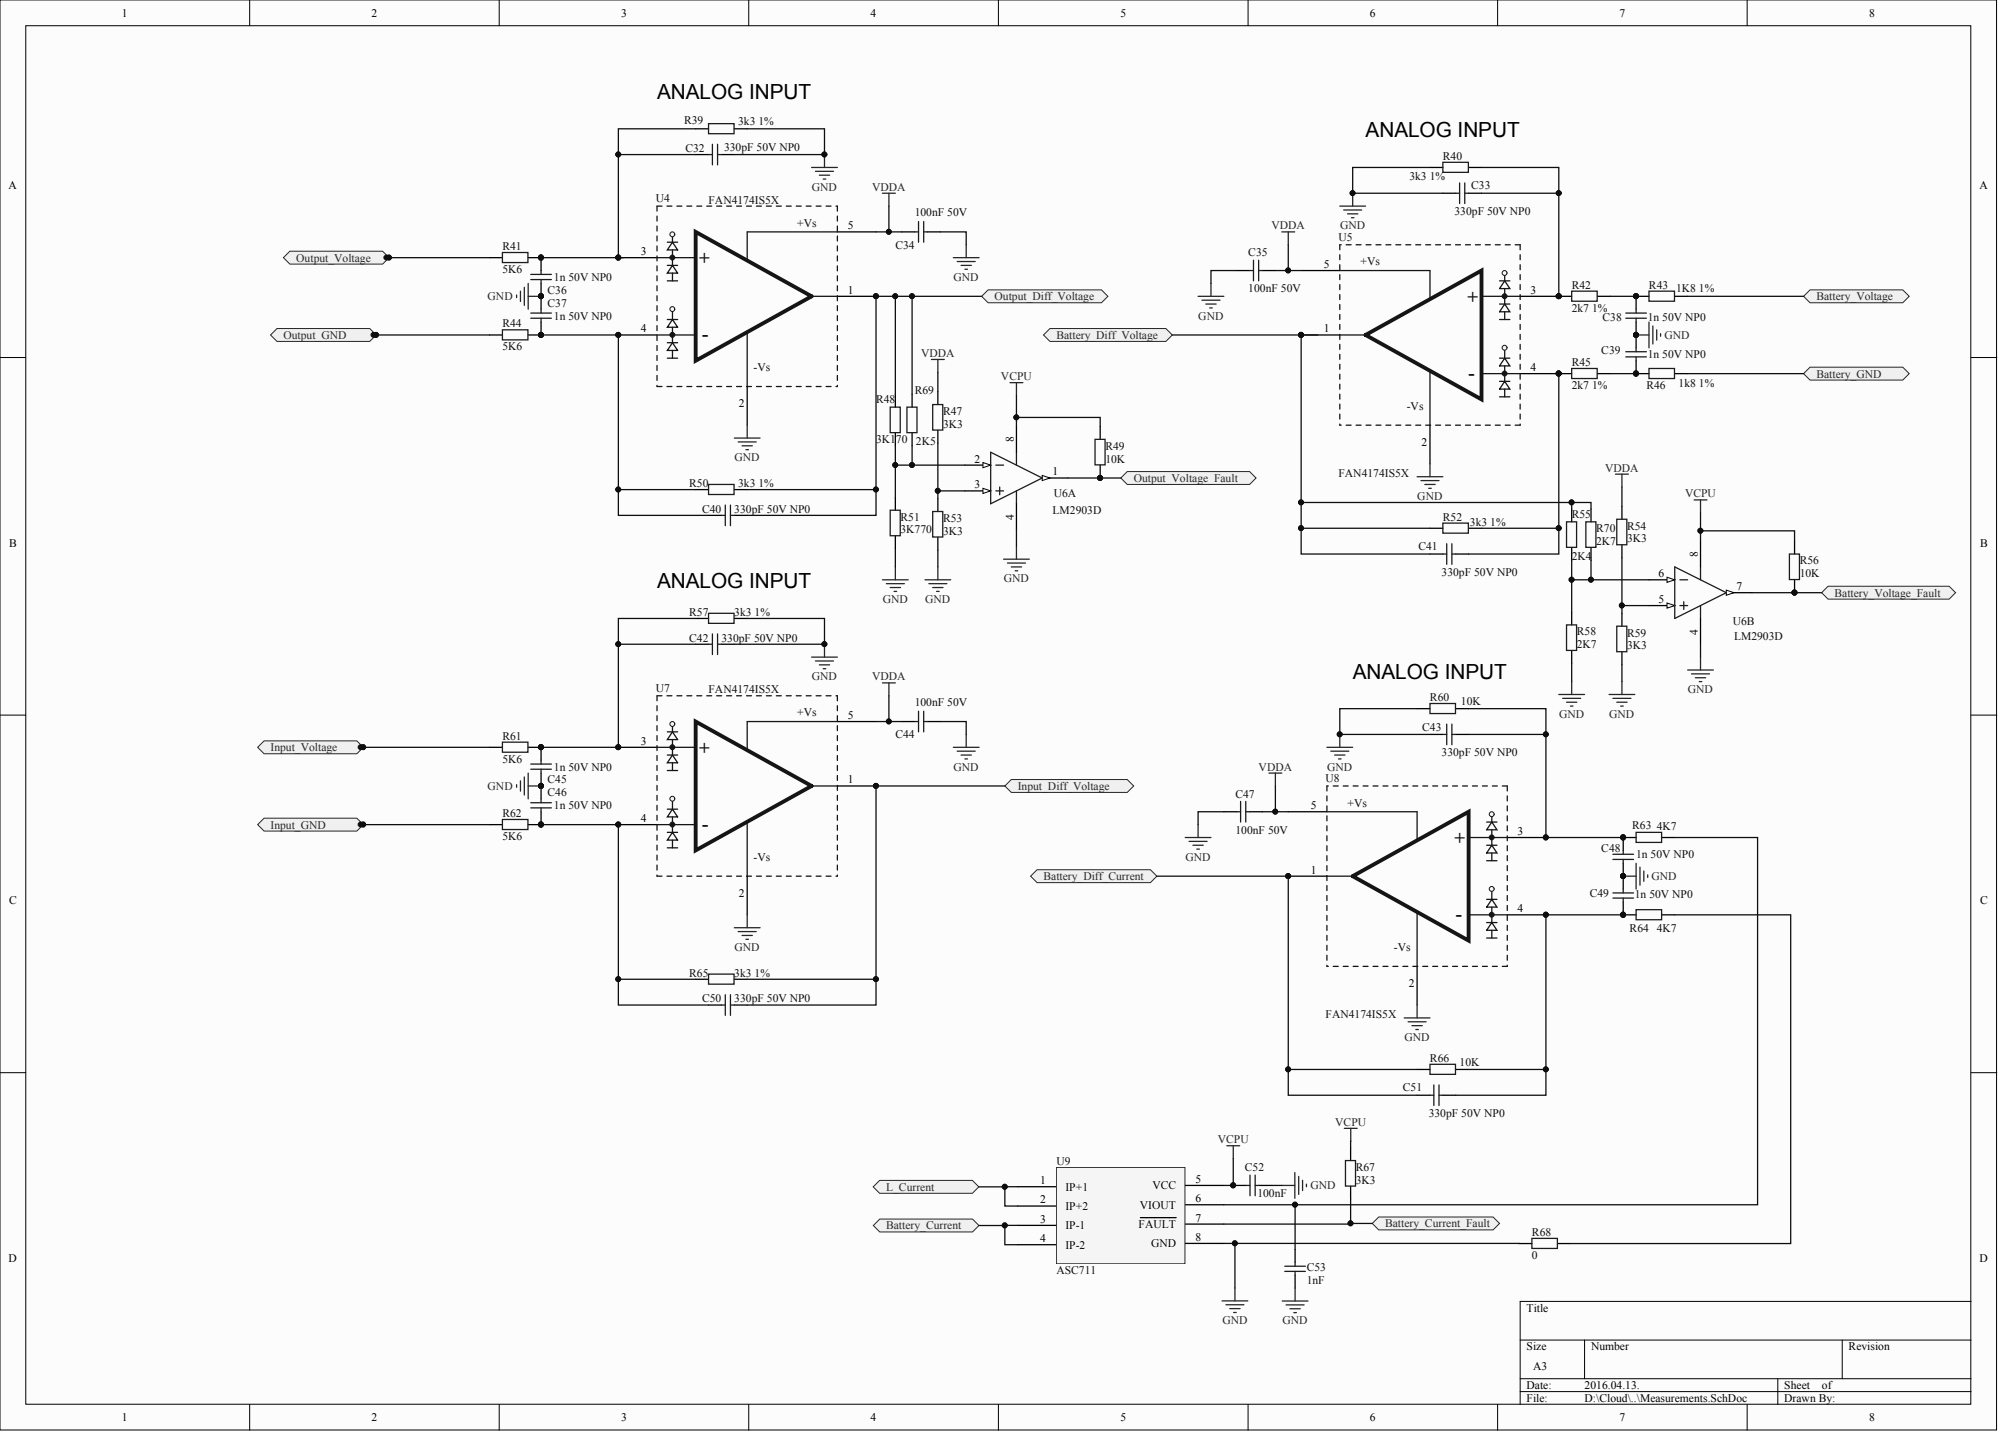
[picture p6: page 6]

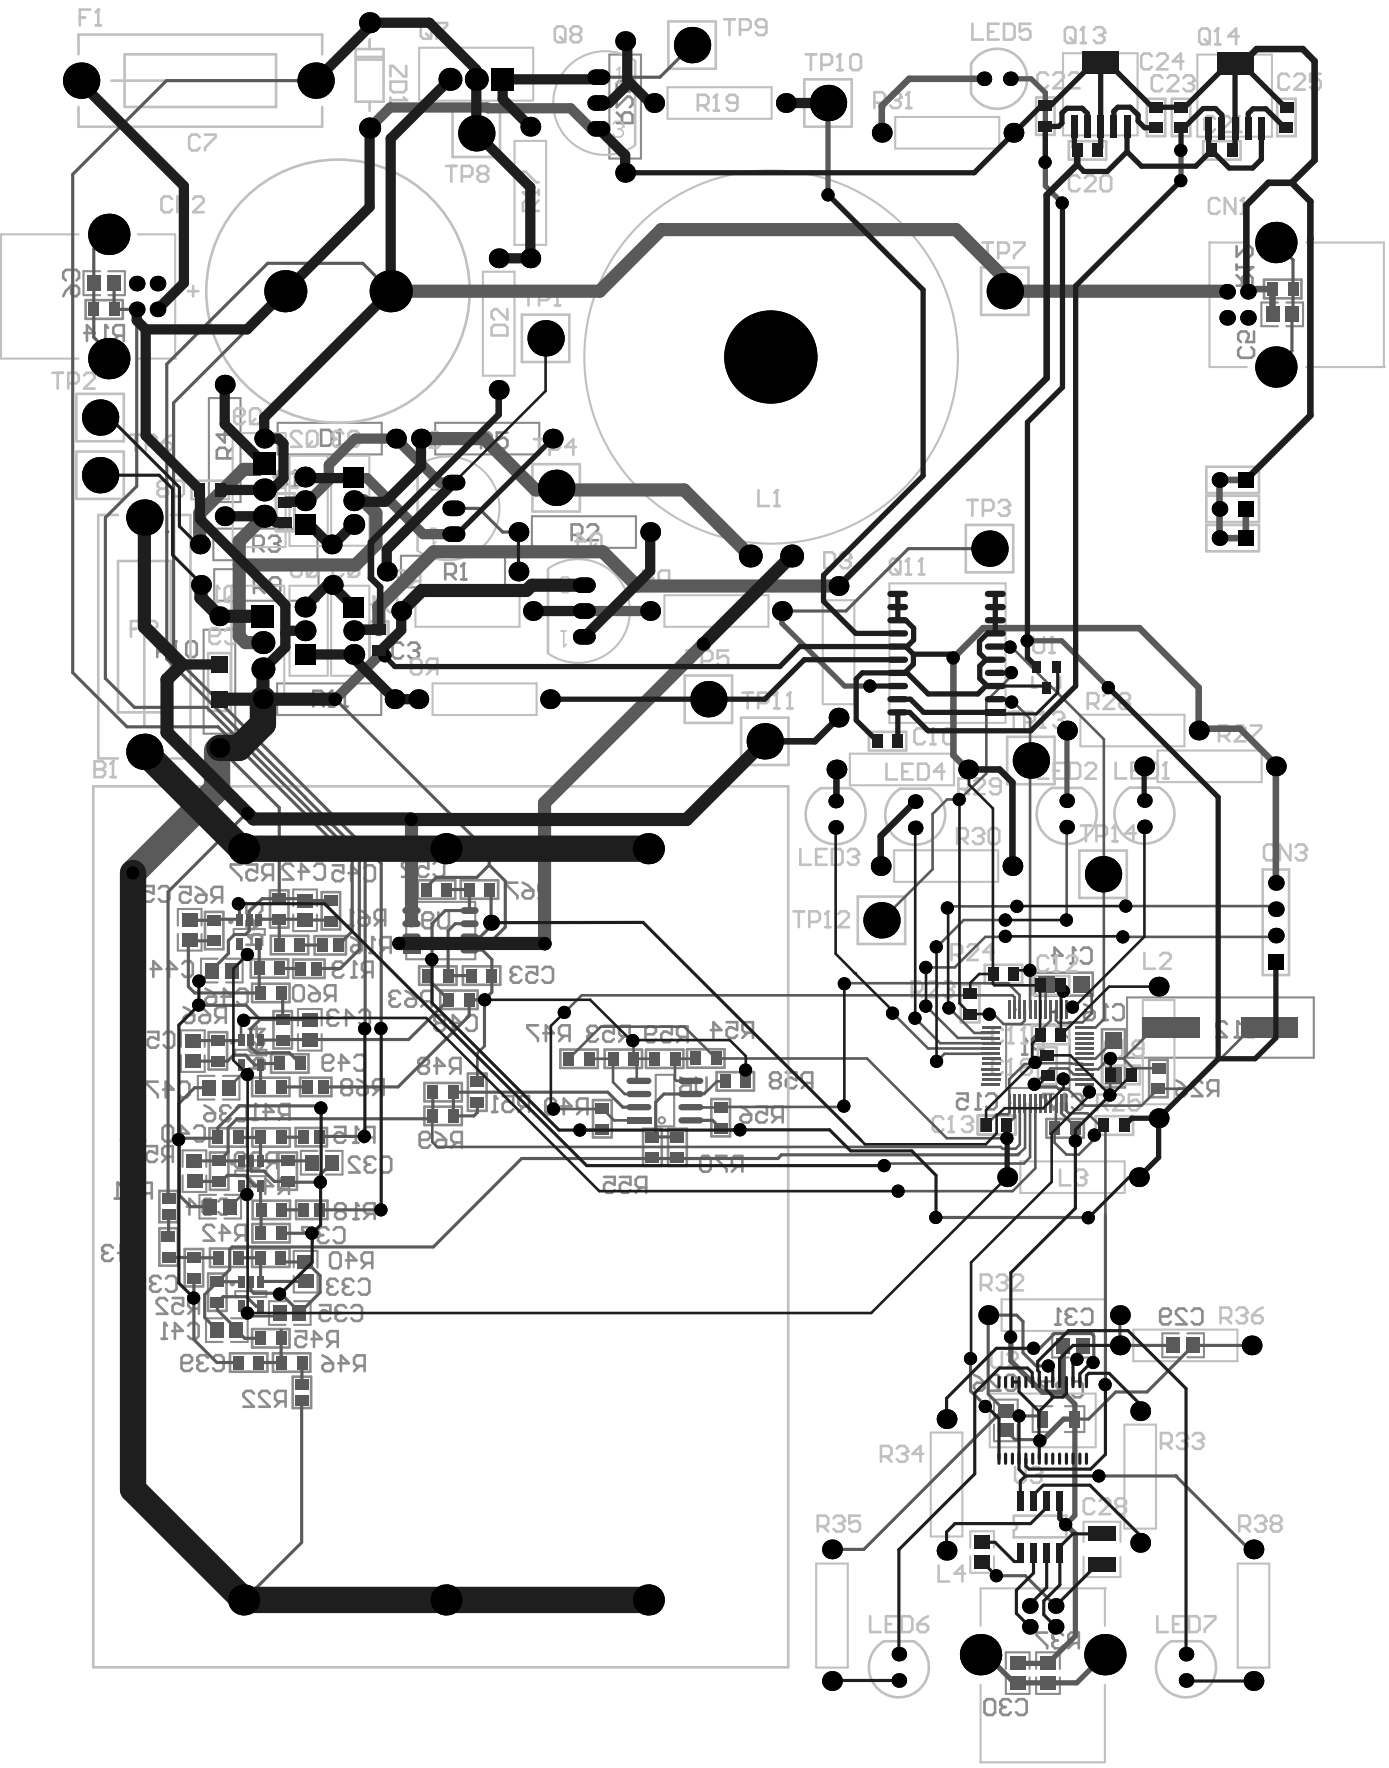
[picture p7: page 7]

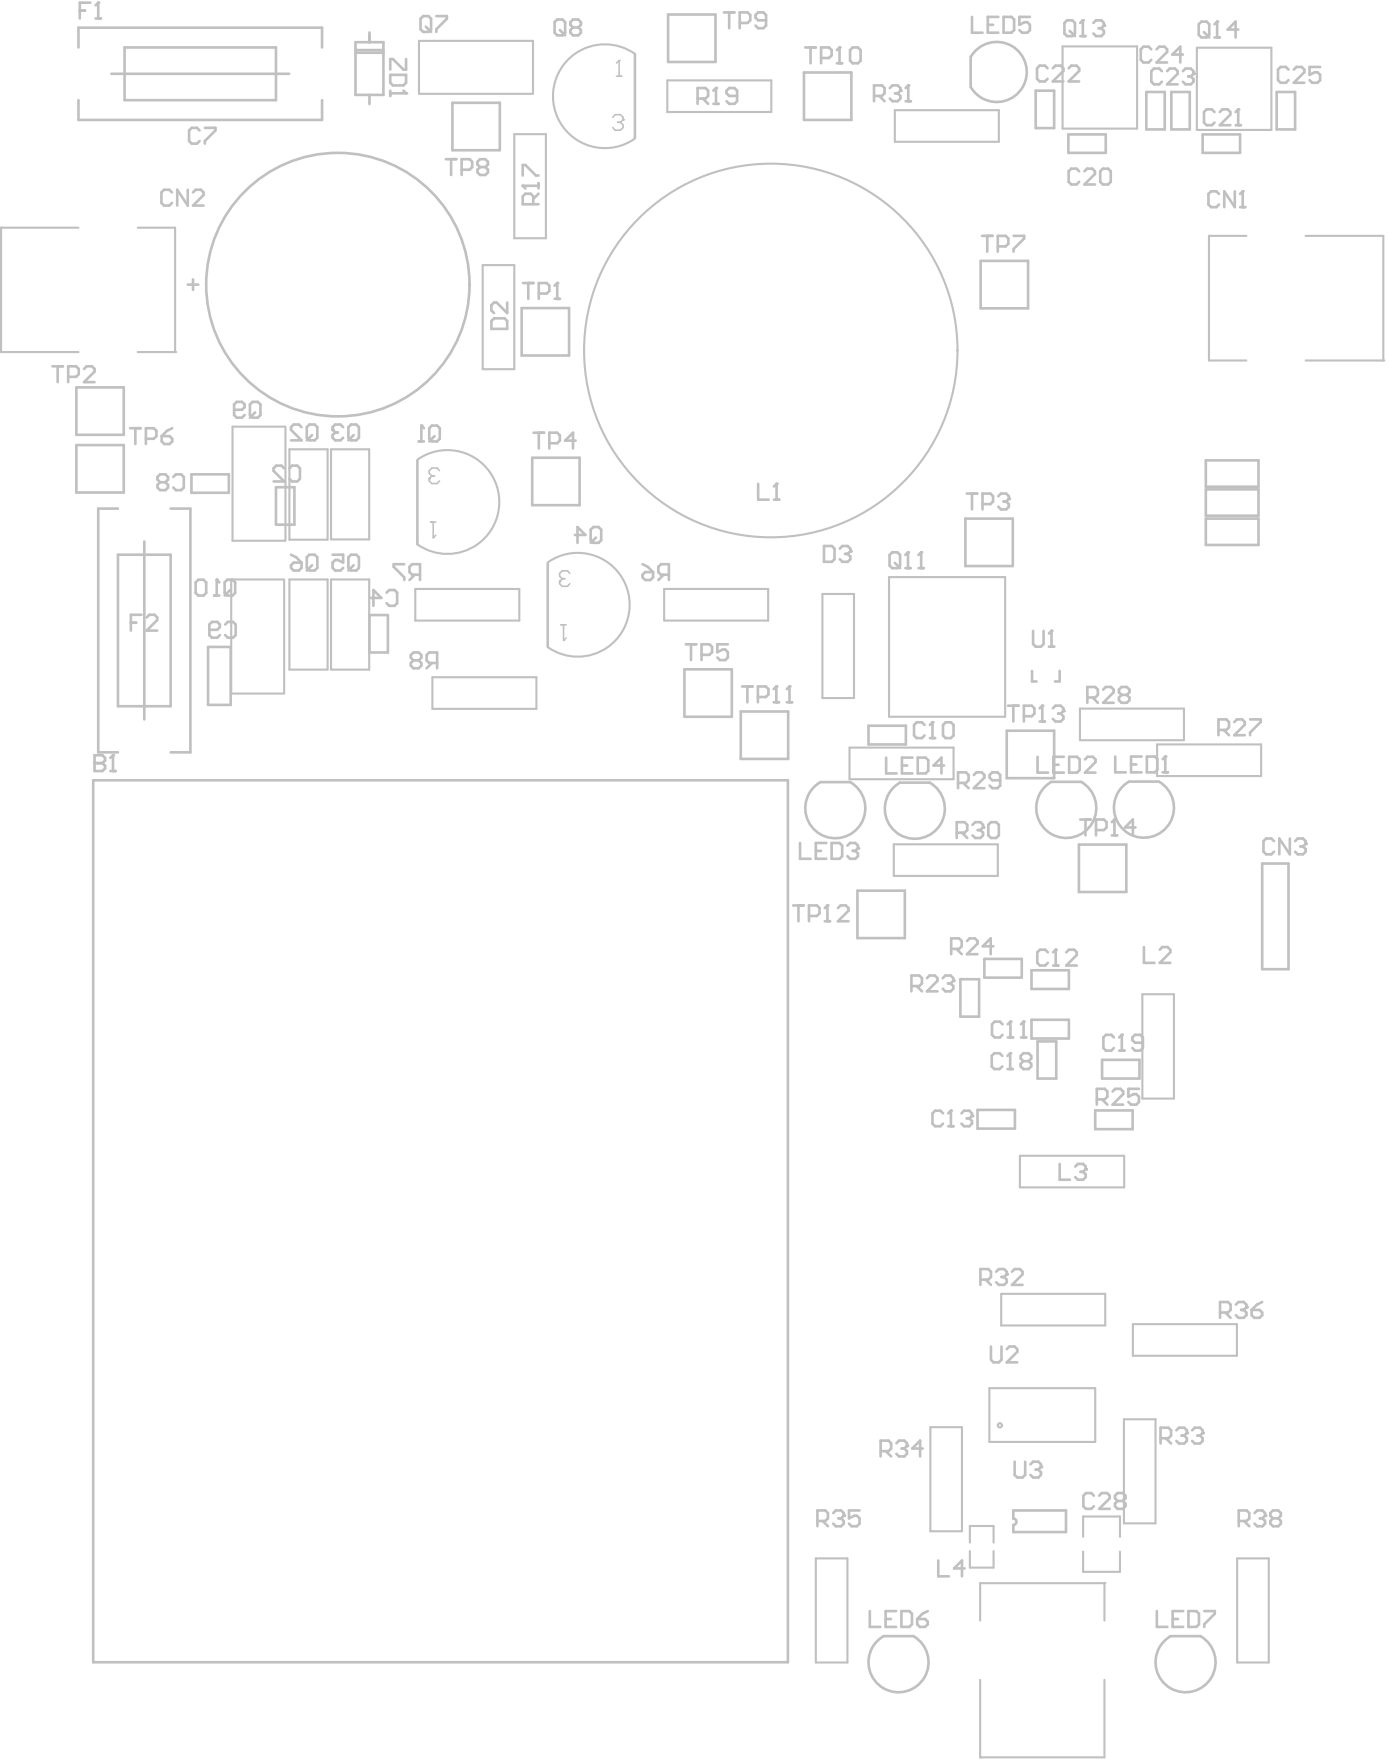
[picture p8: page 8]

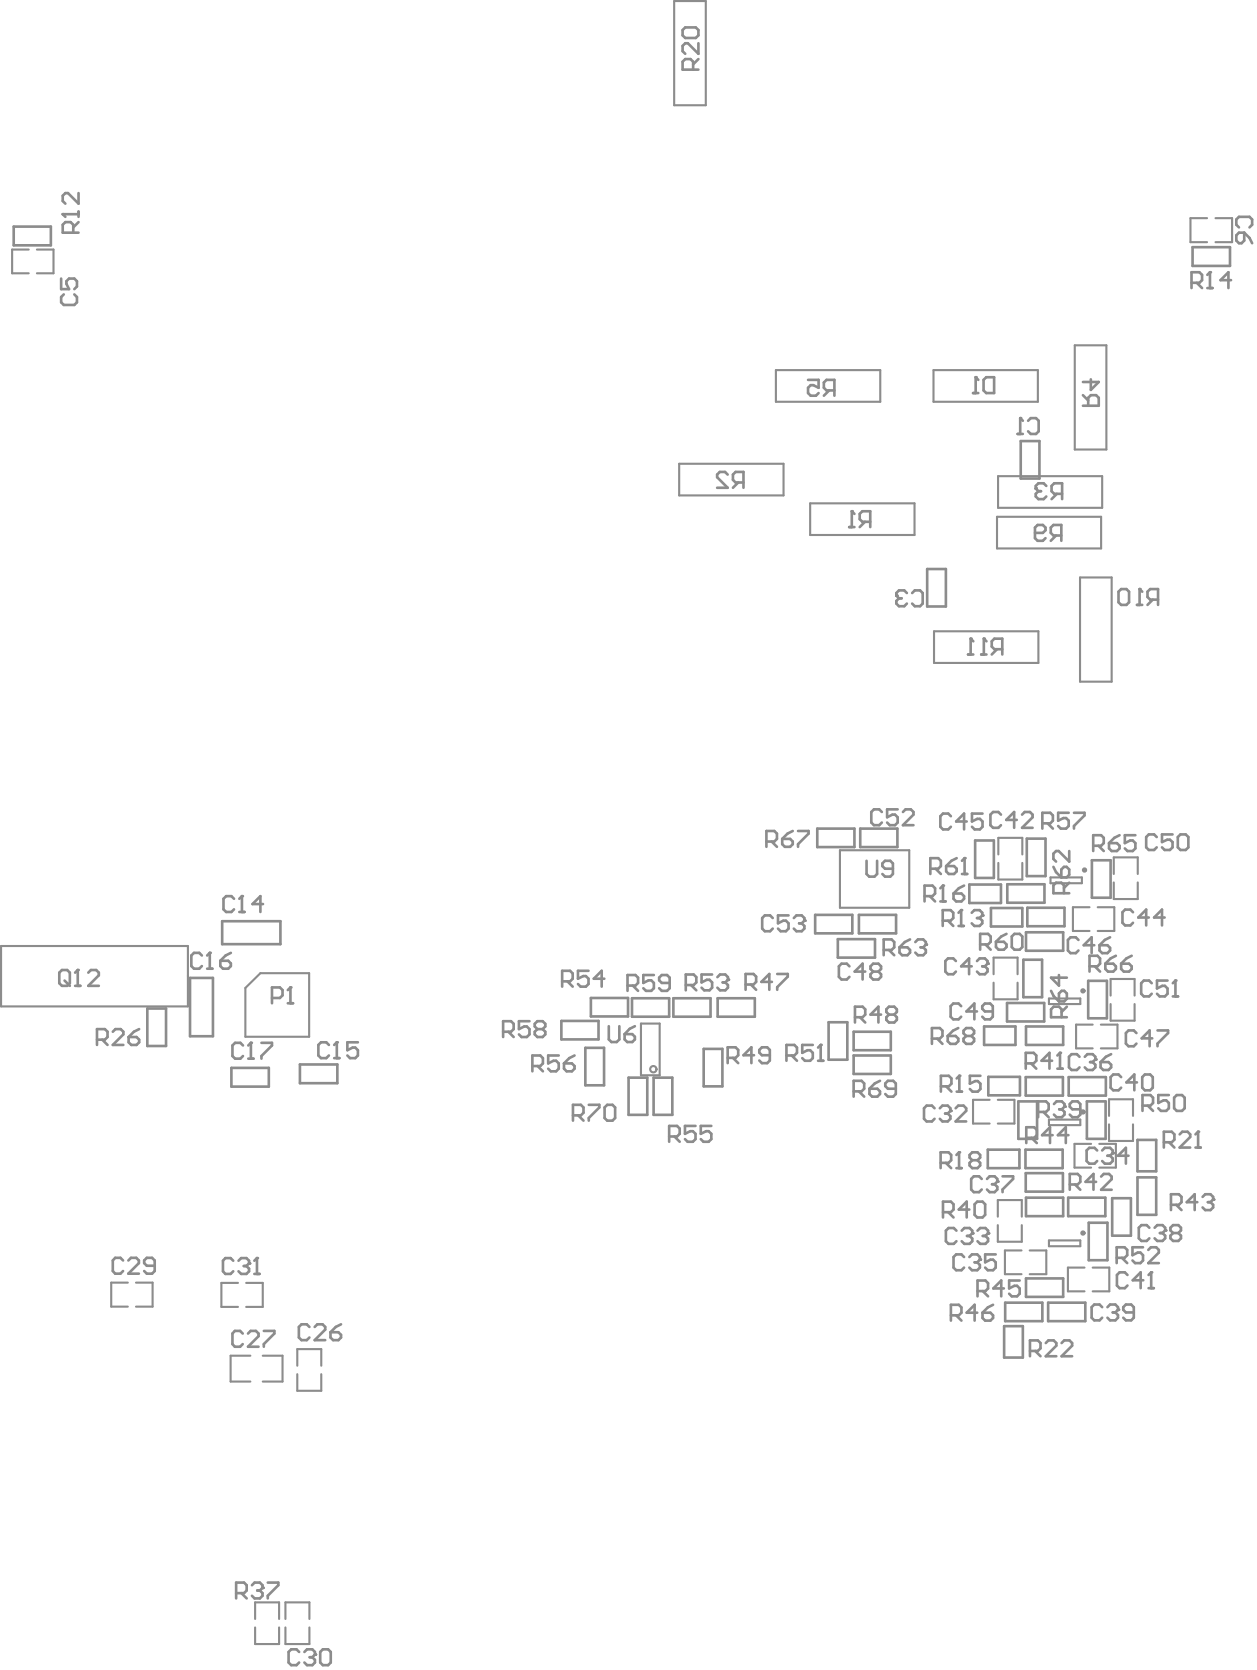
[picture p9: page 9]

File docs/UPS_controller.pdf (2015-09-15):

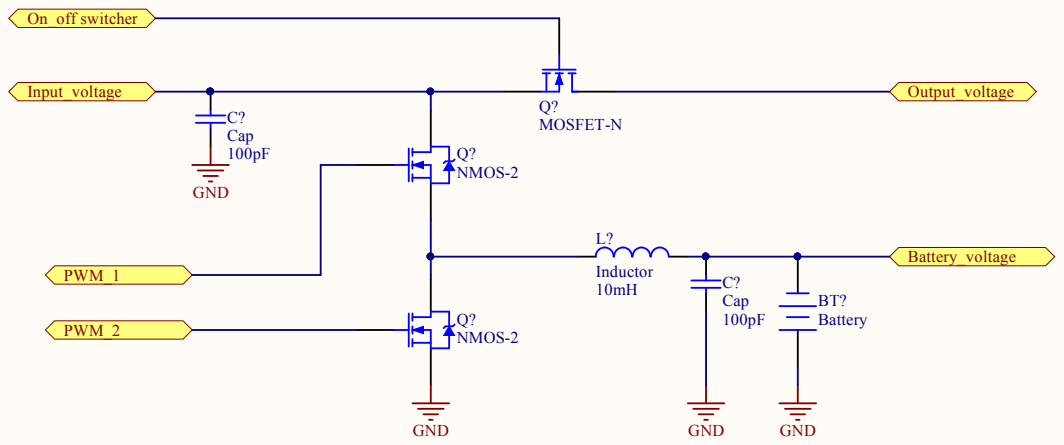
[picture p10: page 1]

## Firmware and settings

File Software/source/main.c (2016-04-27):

#include <PIController.h>
#include "DSP2802x_Device.h"
#include "inic.h"
#include "i2c.h"
#include "HiMon.h"
#include "IQmathLib.h"
#include "bbx.h"
#include "StateMachine.h"

extern Uint16 TZforce;
extern Uint16 TZclear;

/* Timer variables for 10ms 100ms and 1s tasks */
Uint16 sw_timer_1ms;
Uint16 adc_int_cnt;

Uint16 pwm_duty = 0;

void ISR_ILLEGAL(void);

__interrupt void cpu_timer0_isr(void)
{
	sw_timer_1ms++;

	forcePWMLock(TZforce);
	forcePWMRelease(TZclear);

	if(EPwm1Regs.TZFLG.all > 0){
		EALLOW;
		GpioDataRegs.GPBSET.bit.GPIO36 = 1;
		EDIS;
	}
	else{
		EALLOW;
		GpioDataRegs.GPBCLEAR.bit.GPIO36 = 1;
		EDIS;
	}

	if (sw_timer_1ms == 1000){
		//LED1 set after current offset measurement
		GpioDataRegs.GPBSET.bit.GPIO33 = 1;
	}
  // Acknowledge this interrupt to receive more interrupts from group 1
  PieCtrlRegs.PIEACK.all = PIEACK_GROUP1;
}

__interrupt void  adc_isr(void)
{
	stateMachine();
	adc_int_cnt++;
	bbx_trigger();
	AdcRegs.ADCINTFLGCLR.bit.ADCINT1 = 1;		//Clear ADCINT1 flag reinitialize for next SOC
	PieCtrlRegs.PIEACK.all = PIEACK_GROUP1;   // Acknowledge interrupt to PIE
	return;
}

interrupt void ISR_ILLEGAL(void)   // Illegal operation TRAP
{
  // Insert ISR Code here

  // Next two lines for debug only to halt the processor here
  // Remove after inserting ISR Code
  asm("          ESTOP0");
  for(;;);

}

void main(void) {
	EALLOW;

	DeviceInit();	// Device Life support & GPIO mux settings
	initControlValueStructures();

	// Enable ADCINT1 in PIE
	IER |= M_INT1; 						// Enable CPU Interrupt 1

	PieCtrlRegs.PIEIER1.bit.INTx1 = 1;	// Enable INT 1.1 in the PIE
	PieCtrlRegs.PIEIER1.bit.INTx7 = 1;	// Enable TINT0 in the PIE: Group 1 interrupt 7

	EINT;          						// Enable Global interrupt INTM
	ERTM;          						// Enable Global realtime interrupt DBGM

	i2c_force_stop();
	InitTermVars();

	for(;;)
	{
		Serial_mng();
    bbx_background();
	}
}

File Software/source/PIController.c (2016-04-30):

#include "PIController.h"
#include "StateMachine.h"

PI_s batteryCurVls;
PI_s outputVoltVls;

Uint16 duty = 0;

void initControlValueStructures(){

	forcePWMLock(1);
	EPwm1Regs.CMPA.half.CMPA = 750;
	batteryCurVls.output = 0;
	batteryCurVls.Error = 0;
	batteryCurVls.oldError = 0;
	batteryCurVls.Diff = 0;
	batteryCurVls.min_integrator = _IQ20(0.1);
	batteryCurVls.max_integrator = _IQ20(0.9);
	batteryCurVls.P = _IQ20(0.048);
	batteryCurVls.I = _IQ20(0.01231);

	outputVoltVls.output = 0;
	outputVoltVls.Error = 0;
	outputVoltVls.oldError = 0;
	outputVoltVls.Diff = 0;
	outputVoltVls.min_integrator = _IQ14(0.1);
	outputVoltVls.max_integrator = _IQ14(3.0);
	outputVoltVls.P = _IQ14(0.048031);
	outputVoltVls.I = _IQ14(0.01231);
}

void currentController(MEASUREMENT_TYPE current, MEASUREMENT_TYPE Ireference){
	_iq20 multiple_1 = 0;
	_iq20 multiple_2 = 0;
	_iq20 sum = 0;

	//Calculate error
	batteryCurVls.Error = current - Ireference;
	batteryCurVls.Diff = batteryCurVls.Error - batteryCurVls.oldError;

	multiple_1 = _IQ20mpyIQX(batteryCurVls.Error, 14, batteryCurVls.I, 20);
	multiple_2 = _IQ20mpyIQX(batteryCurVls.Diff, 14, batteryCurVls.P, 20);
	sum = multiple_1 + multiple_2;

	/*ÁRAMSZABÁLYZÓ KEZDETE*/
	//Calculate sum(Ierror*I + dIerror * Ap)
	batteryCurVls.output += sum;
	//perform z^-1
	batteryCurVls.oldError = batteryCurVls.Error;
	//perform saturation on integrator output
	if (batteryCurVls.output > batteryCurVls.max_integrator){
		batteryCurVls.output = batteryCurVls.max_integrator;
	}
	if (batteryCurVls.output < batteryCurVls.min_integrator){
		batteryCurVls.output = batteryCurVls.min_integrator;
	}
	/*ÁRAMSZABÁLYZÓ VÉGE*/
	duty = _IQ1mpyIQX(batteryCurVls.output, 20, (long)EPwm1Regs.TBPRD, 0) >> 1;
	EPwm1Regs.CMPA.half.CMPA = EPwm1Regs.TBPRD - duty;	//set PWM compare register
}


MEASUREMENT_TYPE outputVoltageController(MEASUREMENT_TYPE voltage, MEASUREMENT_TYPE Ureference){
	_iq14 multiple_1 = 0;
	_iq14 multiple_2 = 0;
	_iq14 sum = 0;

	//Calculate error
	outputVoltVls.Error = Ureference - voltage;
	outputVoltVls.Diff = outputVoltVls.Error - outputVoltVls.oldError;

	multiple_1 = _IQ14mpyIQX(outputVoltVls.Error, 14, outputVoltVls.I, 14);
	multiple_2 = _IQ14mpyIQX(outputVoltVls.Diff, 14, outputVoltVls.P, 14);
	sum = multiple_1 + multiple_2;


	/*FESZÜLTSÉG szabályzó KEZDETE*/
	//Calculate sum(Ierror*I + dIerror * Ap)
	outputVoltVls.output += sum;
	//perform z^-1
	outputVoltVls.oldError = outputVoltVls.Error;
	//perform saturation on integrator output
	if (outputVoltVls.output > outputVoltVls.max_integrator){
		outputVoltVls.output = outputVoltVls.max_integrator;
	}
	/*FESZÜLTSÉG szabályzó VÉGE*/
	return outputVoltVls.output;
}


batteryVoltageController(MEASUREMENT_TYPE batteryVoltage, MEASUREMENT_TYPE Ureference){

}

Uint16 PWMTest(Uint16 pwm_counter){

	Uint16 pwm_duty = 0;
	Uint16 pwm_counter_max = 100;
	Uint16 down = 1;

	if(pwm_counter >= pwm_counter_max){
		pwm_counter = 0;
		if (pwm_duty < 1500)
		{
			if(down == 1){
				pwm_duty -= 10;
			}
			else{
				pwm_duty += 10;
			}
		}
		if(pwm_duty <= 10){
			pwm_duty = 1;
			down = 0;
		}
		if(pwm_duty >= 1500 && pwm_duty < 2000){
			pwm_duty = 1499;
			down = 1;
		}
	}
	return pwm_duty;
}

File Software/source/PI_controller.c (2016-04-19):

#include "PI_controller.h"

PI_s batteryCurrentControlValues;

void initControlValueStructures(){
	batteryCurrentControlValues.measured = 0;
	batteryCurrentControlValues.measured_old = 0;
	batteryCurrentControlValues.min_integrator = 0;
	batteryCurrentControlValues.max_integrator = 1;
	batteryCurrentControlValues.P = MEASUREMENT_CONVERSION(0);
	batteryCurrentControlValues.I = MEASUREMENT_CONVERSION(0);
}

void currentController(MEASUREMENT_TYPE current){
	MEASUREMENT_TYPE duty = 0;
	MEASUREMENT_TYPE Ierror = 0;
	MEASUREMENT_TYPE Ireference = MEASUREMENT_CONVERSION(1.0);

	//Calculate error
	Ierror = Ireference - current;
	batteryCurrentControlValues.measured = Ierror;

	/*ÁRAMSZABÁLYZÓ KEZDETE*/
	//Calculate sum(Ierror*I + dIerror * Ap)
	batteryCurrentControlValues.output += batteryCurrentControlValues.measured *
										  batteryCurrentControlValues.I +
										  (batteryCurrentControlValues.measured - batteryCurrentControlValues.measured_old) *
										  batteryCurrentControlValues.P;
	//perform z^-1
	batteryCurrentControlValues.measured_old = batteryCurrentControlValues.measured;

	//perform saturation on integrator output
	if (batteryCurrentControlValues.output > batteryCurrentControlValues.max_integrator){
		batteryCurrentControlValues.output = batteryCurrentControlValues.max_integrator;
	}
	if (batteryCurrentControlValues.output < batteryCurrentControlValues.min_integrator){
		batteryCurrentControlValues.output = batteryCurrentControlValues.min_integrator;
	}
	/*ÁRAMSZABÁLYZÓ VÉGE*/

	duty = batteryCurrentControlValues.output;
	EPwm1Regs.CMPA.half.CMPA = (Uint16)(EPwm1Regs.TBPRD * duty);	//set PWM compare register
}

Uint16 PWMTest(Uint16 pwm_counter){

	Uint16 pwm_duty = 0;
	Uint16 pwm_counter_max = 100;
	Uint16 down = 1;

	if(pwm_counter >= pwm_counter_max){
		pwm_counter = 0;
		if (pwm_duty < 1500)
		{
			if(down == 1){
				pwm_duty -= 10;
			}
			else{
				pwm_duty += 10;
			}
		}
		if(pwm_duty <= 10){
			pwm_duty = 1;
			down = 0;
		}
		if(pwm_duty >= 1500 && pwm_duty < 2000){
			pwm_duty = 1499;
			down = 1;
		}
	}
	return pwm_duty;
}

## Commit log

2015-09-14 Ups controller schematic with half bridge
    [UPS_controller.SchDoc]
2015-09-15 Create pdf from schematic
    [UPS_controller.SchDoc]
2015-09-15 Create workspace for the project
    [UPS_controller.SchDoc]
2015-09-16 Voltage monitor circuit added
    [VoltageMonitor.SchDoc]
2015-09-16 Voltage monitor circuit wired
    [AXON-UPS.PrjPcb, UPS_controller.SchDoc]
2016-02-13 schematic, drawing new parts
    [AXON-UPS.PrjPcb, BufferDriver.SchDoc, FetController.SchDoc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]
2016-02-13 added műveleti erősítő és tápok
    [AXON-UPS.PrjPcb, BufferDriver.SchDoc, FetController.SchDoc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]
2016-02-13 Added processor
    [AXON-UPS.PrjPcb, BufferDriver.SchDoc, FetController.SchDoc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]
2016-02-14 Processor táp és pwm bekötés
    [AXON-UPS.PrjPcb, BufferDriver.SchDoc, FetController.SchDoc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]
2016-02-16 FTDI chip
    [AXON-UPS.PrjPcb, BufferDriver.SchDoc, FTDI.SchDoc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]
2016-02-17 András library
    [MERES.PcbLib, MERES.SchLib, Volt_meter.SchDoc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]
2016-02-17 Konzultáció utáni hibajavítások, plusz kapcsolási rajzok
    [AXON-UPS.PrjPcb, BufferDriver.SchDoc, FetController.SchDoc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]
2016-02-18 Hierarchy Added measurements Komparátor needed
    [AXON-UPS.PrjPcb, BufferDriver.SchDoc, FetController.SchDoc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]
2016-02-19 added comparator
    [BufferDriver.SchDoc, FetController.SchDoc, Measurements.SchDoc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]
2016-02-21 almost finally schematic
    [AXON-UPS.PrjPcb, BufferDriver.SchDoc, FetController.SchDoc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]
2016-02-21 all res value changed on measurment sheet
    [Measurements.SchDoc, Processor.SchDoc]
2016-02-21 tápszűrő induktivitások lomex száma
    [Measurements.SchDoc, Processor.SchDoc, UPS_controller.SchDoc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]
2016-02-22 konzultáció
    [BufferDriver.SchDoc, FetController.SchDoc, Measurements.SchDoc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]
2016-02-22 PCB start
    [AXON-UPS.PrjPcb, BufferDriver.SchDoc, FetController.SchDoc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]
2016-02-23 PCB előkészületek
    [UPS.PcbDoc, UPS_controller.SchDoc, hallglib.SchLib]
2016-02-24 Néhány PCB elem rendberakása, PCB design rule-ok beállítása, néhány elem elhelyezése
    [MERES.PcbLib, Measurements.SchDoc, UPS.PcbDoc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]
2016-02-24 nagy áramú alaktrészek elhelyezve
    [MERES.PcbLib, Measurements.SchDoc, Processor.SchDoc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]
2016-02-25 Routing 45%
    [Processor.SchDoc, UPS_controller.SchDoc]
2016-02-27 Routing 85%, processzor bekötése még vissza van
    [Measurements.SchDoc, Processor.SchDoc, ftdi_ok.SchDoc]
2016-02-28 Routolás kész :)
    [MERES.PcbLib, Processor.SchDoc]
2016-02-29 gyártás előtti állapot, még1 utsó ellenőrzés kellhet :)
    [AXON-UPS.PrjPcb, UPS_controller.SchDoc]
2016-03-01 output fájlok
    [BOM_order-AXON-UPS.xls, BOM_place-AXON-UPS.xls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]
2016-04-02 deleted CSS project, added Szákó solution :)
    [Measurements.SchDoc]
2016-04-03 Try to enable PWM, added upload and monitor softwares
2016-04-10 Measure voltages, PWM led demo
2016-04-14 pwm bug fixed
2016-04-14 PWM = 0 at init
2016-04-17 Added LED1, measurements calculation corrections
    [adcMeasurements.h, inic.c, main.c]
2016-04-25 StateMachine, PI controller voltage
2016-04-25 PI current controller good params, StateMachine working
